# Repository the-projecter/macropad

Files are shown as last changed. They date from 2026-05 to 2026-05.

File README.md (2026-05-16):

# RP2040 Macro Pad

A custom 3x3 macro pad project based on the Seeed Studio RP2040 microcontroller.

The macro pad features 9 Cherry MX switches, arranged in a 3x3 matrix, a 0.91" OLED display (128x32 px), and 12 WS2812B RGB LEDs for underglow lighting effects.

The firmware is programmed using QMK and includes customizable keymaps, OLED status display support, and RGB lighting effects.

## Sponsor
<p align="left">
  
</p>

This project is proudly sponsored by
[NextPCB](https://www.nextpcb.com/?code=Projecter). NextPCB is my first sponsor and this project was made possible through their support.
If you are working on a similar project, then get your first PCB for only 0.1$.

## Hardware

* Seeed Studio RP2040

* 9x Cherry MX switches

* 0.91" OLED display (128x32 px)

* 12x WS2812B RGB LEDs

* custom designed PCB

## Software

* QMK Firmware

* Custom keymaps

* OLED support

* RGB underglow effects

## Finished Project

<p align="left">
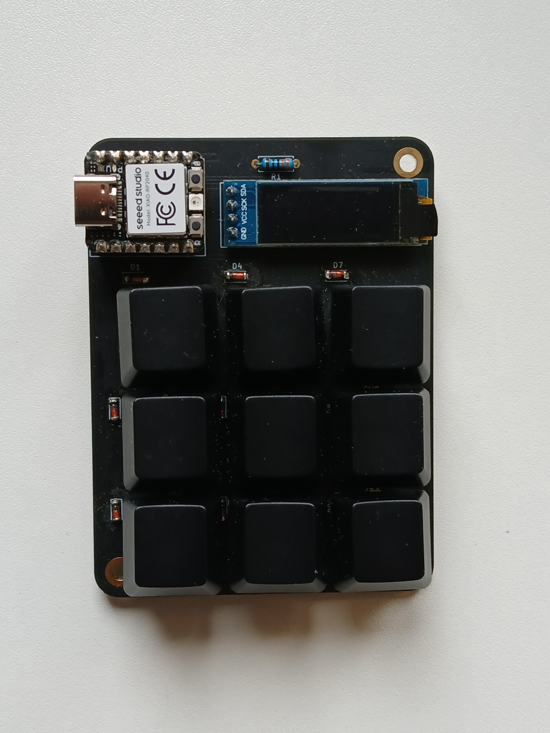
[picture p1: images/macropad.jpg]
  
</p>

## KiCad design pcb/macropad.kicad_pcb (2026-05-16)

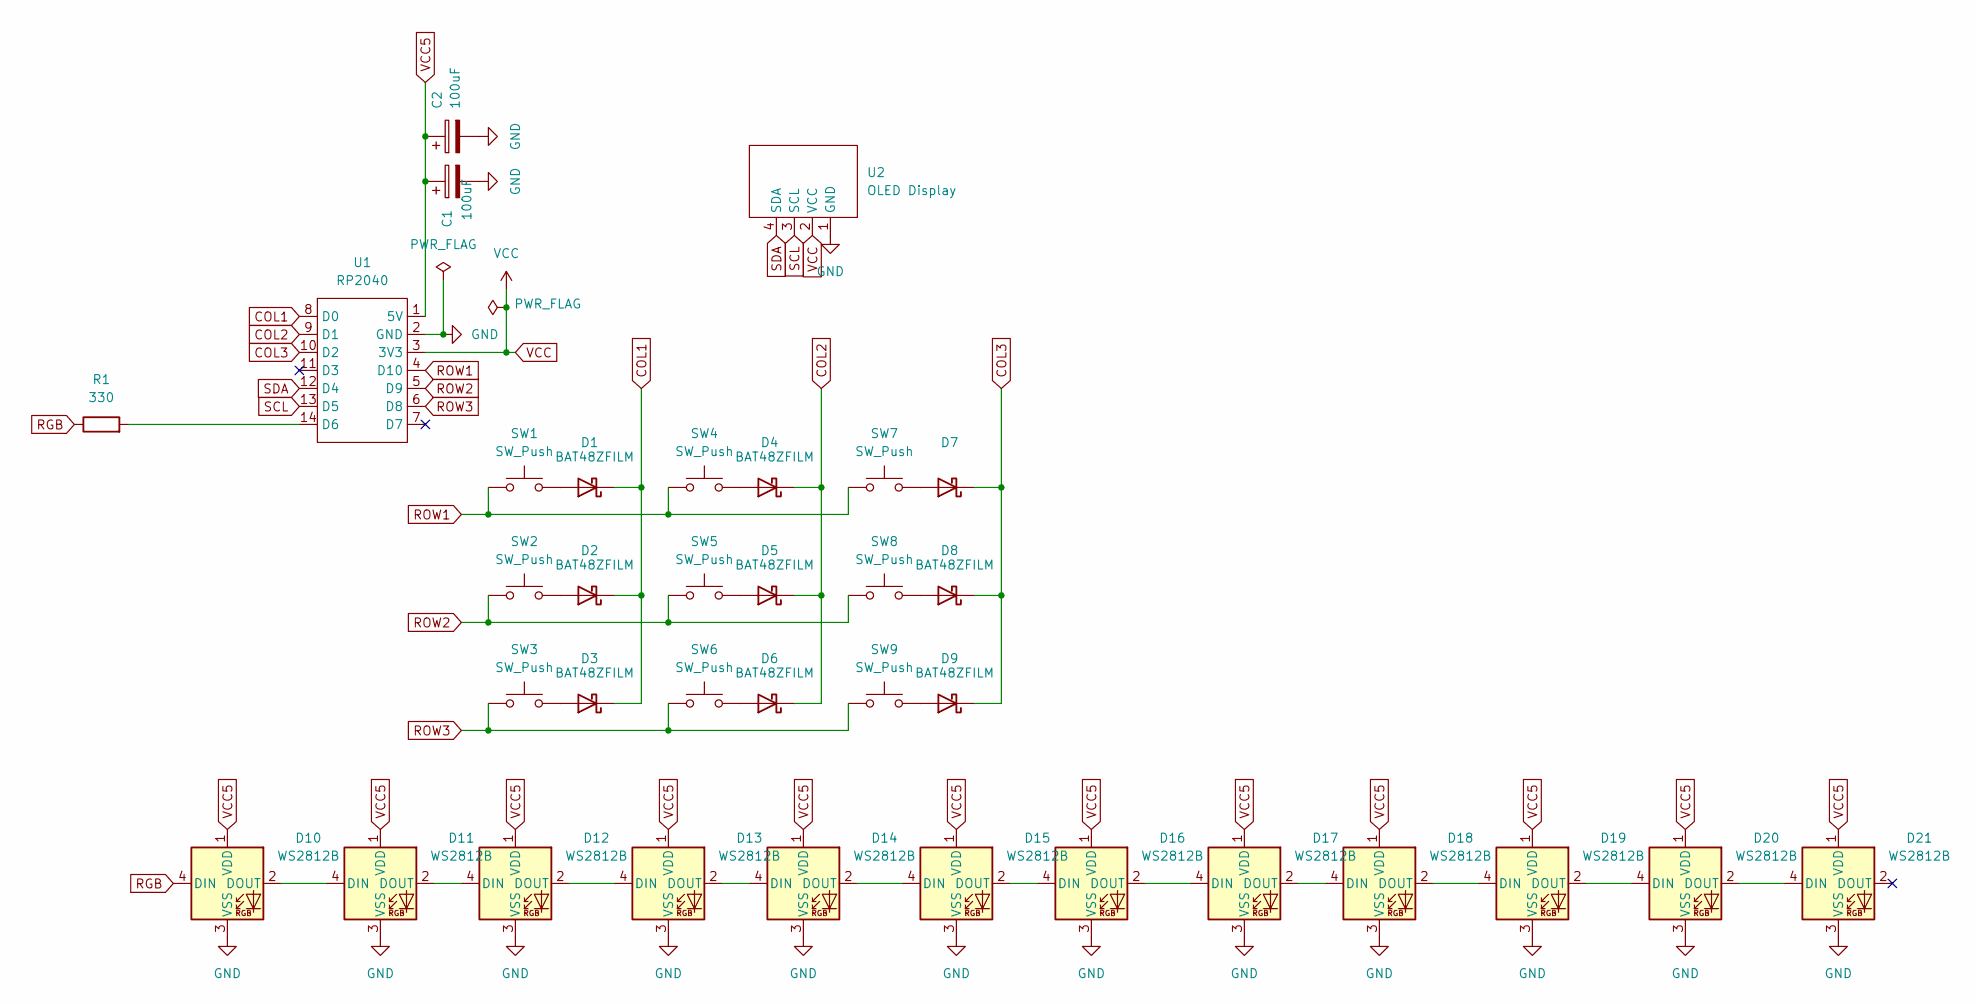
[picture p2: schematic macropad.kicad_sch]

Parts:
C1, C2: 100uF; CP_Radial_D6.3mm_P2.50mm
D1, D2, D3, D4, D5, D6, D7, D8, D9: BAT48ZFILM; D_SOD-123
D10, D11, D12, D13, D14, D15, D16, D17, D18, D19, D20, D21: WS2812B; LED_WS2812B_PLCC4_5.0x5.0mm_P3.2mm
R1: 330; R_Axial_DIN0207_L6.3mm_D2.5mm_P7.62mm_Horizontal
SW1, SW2, SW3, SW4, SW5, SW6, SW7, SW8, SW9: SW_Push; SW_Cherry_MX_1.00u_Plate
U1: RP2040; RP2040_MK
U2: OLED Display; 0.91__OLED_Display

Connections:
COL1: D1.1 (K), D2.1 (K), D3.1 (K), U1.8 (D0)
COL2: D4.1 (K), D5.1 (K), D6.1 (K), U1.9 (D1)
COL3: D7.1 (K), D8.1 (K), D9.1 (K), U1.10 (D2)
GND: C1.2, C2.2, D10.3 (VSS), D11.3 (VSS), D12.3 (VSS), D13.3 (VSS), D14.3 (VSS), D15.3 (VSS), D16.3 (VSS), D17.3 (VSS), D18.3 (VSS), D19.3 (VSS), D20.3 (VSS), D21.3 (VSS), U1.2 (GND), U2.1 (GND)
unnamed: D1.2 (A), SW1.2
unnamed: D2.2 (A), SW2.2
unnamed: D3.2 (A), SW3.2
unnamed: D4.2 (A), SW4.2
unnamed: D5.2 (A), SW5.2
unnamed: D6.2 (A), SW6.2
unnamed: D7.2 (A), SW7.2
unnamed: D8.2 (A), SW8.2
unnamed: D9.2 (A), SW9.2
unnamed: D10.2 (DOUT), D11.4 (DIN)
unnamed: D11.2 (DOUT), D12.4 (DIN)
unnamed: D12.2 (DOUT), D13.4 (DIN)
unnamed: D13.2 (DOUT), D14.4 (DIN)
unnamed: D14.2 (DOUT), D15.4 (DIN)
unnamed: D15.2 (DOUT), D16.4 (DIN)
unnamed: D16.2 (DOUT), D17.4 (DIN)
unnamed: D17.2 (DOUT), D18.4 (DIN)
unnamed: D18.2 (DOUT), D19.4 (DIN)
unnamed: D19.2 (DOUT), D20.4 (DIN)
unnamed: D20.2 (DOUT), D21.4 (DIN)
unnamed: R1.2, U1.14 (D6)
RGB: D10.4 (DIN), R1.1
ROW1: SW1.1, SW4.1, SW7.1, U1.4 (D10)
ROW2: SW2.1, SW5.1, SW8.1, U1.5 (D9)
ROW3: SW3.1, SW6.1, SW9.1, U1.6 (D8)
SCL: U1.13 (D5), U2.3 (SCL)
SDA: U1.12 (D4), U2.4 (SDA)
VCC: U1.3 (3V3), U2.2 (VCC)
VCC5: C1.1, C2.1, D10.1 (VDD), D11.1 (VDD), D12.1 (VDD), D13.1 (VDD), D14.1 (VDD), D15.1 (VDD), D16.1 (VDD), D17.1 (VDD), D18.1 (VDD), D19.1 (VDD), D20.1 (VDD), D21.1 (VDD), U1.1 (5V)

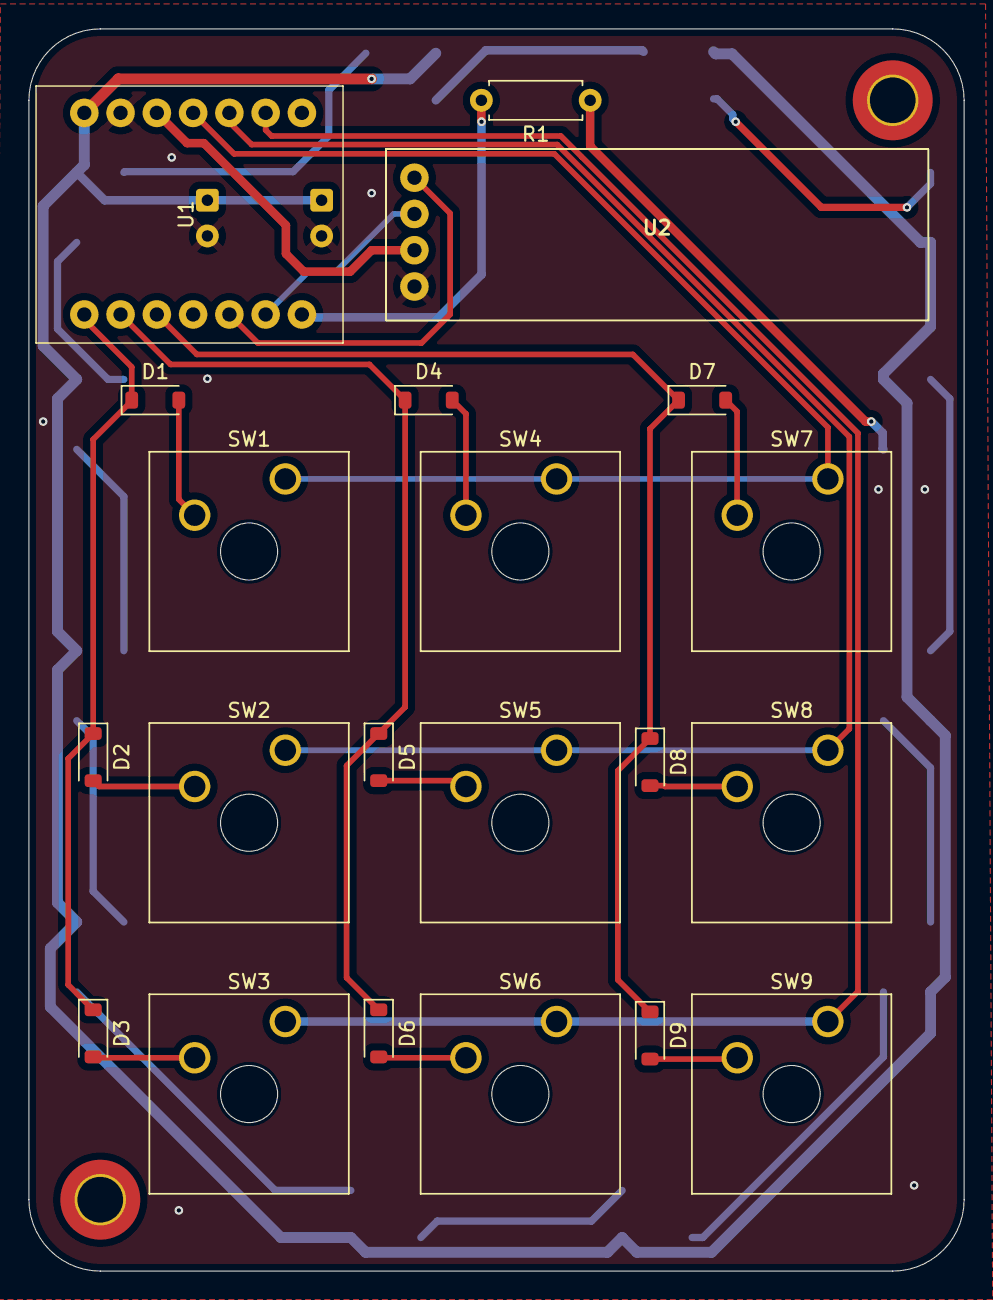
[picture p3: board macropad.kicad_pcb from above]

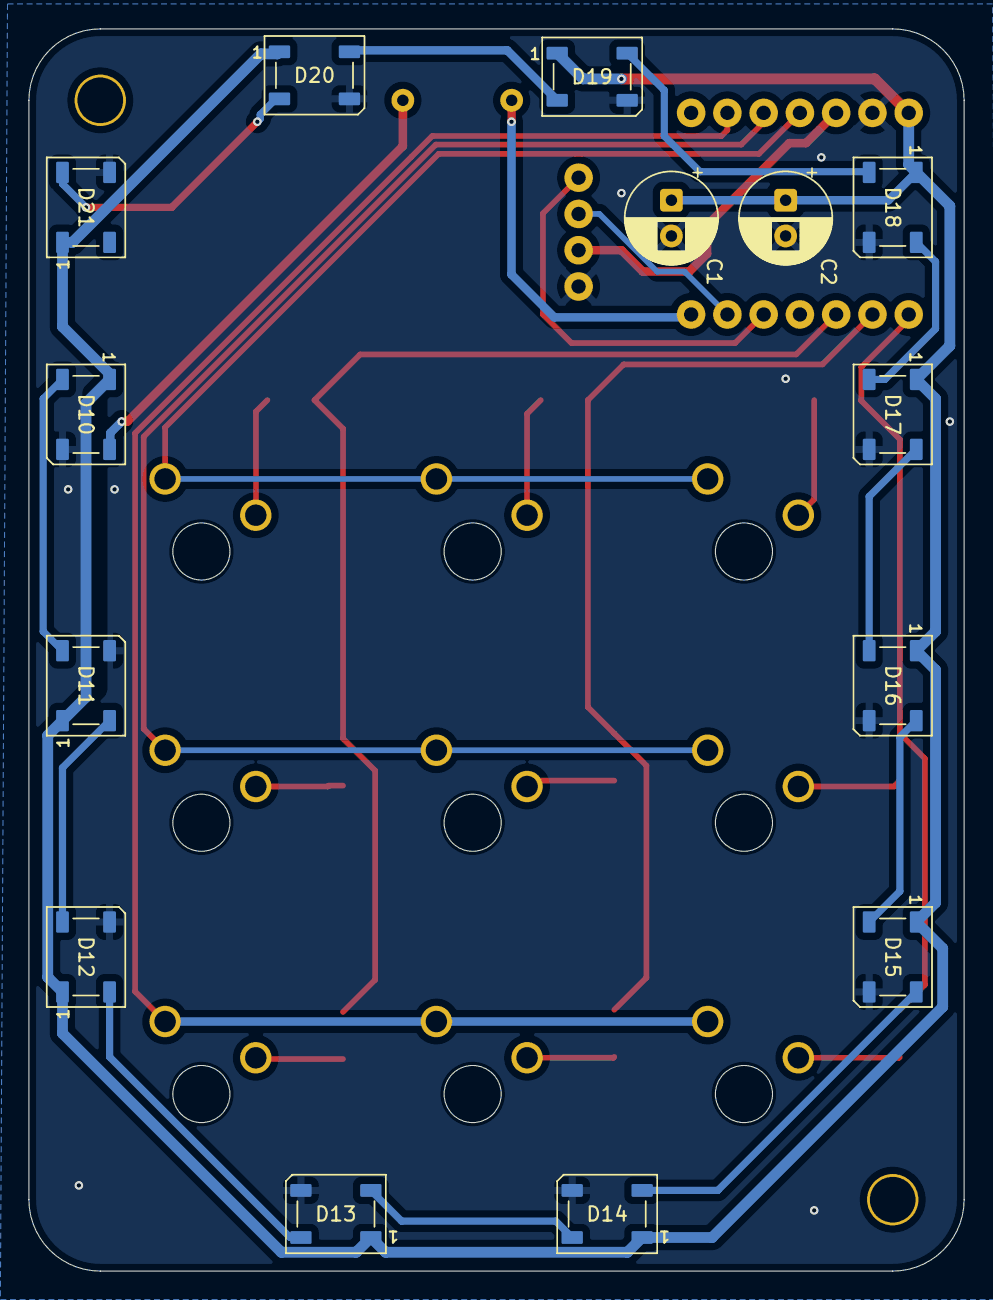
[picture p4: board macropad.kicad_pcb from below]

Board: 2 copper layers, 65.5 x 87.0 mm, 35 parts (14 on the bottom side), 33 nets.

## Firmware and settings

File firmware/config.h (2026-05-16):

#pragma once

#define RGBLIGHT_LED_COUNT 12
#define WS2812_DI_PIN GP0

#define OLED_DISPLAY_128X32
#define OLED_IC OLED_IC_SSD1306

#define RGBLIGHT_LIMIT_VAL 120
#define RGBLIGHT_EFFECT_RAINBOW_MOOD
#define RGBLIGHT_EFFECT_BREATHING
#define RGBLIGHT_EFFECT_STATIC_GRADIENT

#define I2C1_SDA_PIN GP6
#define I2C1_SCL_PIN GP7

#define MATRIX_ROWS 3
#define MATRIX_COLS 3
